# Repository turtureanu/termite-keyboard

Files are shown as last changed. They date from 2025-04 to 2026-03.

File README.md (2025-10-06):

# Termite

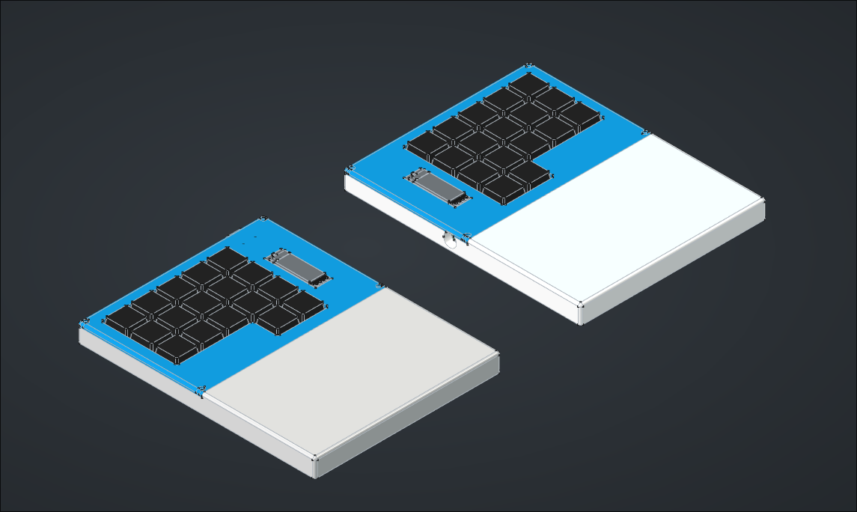
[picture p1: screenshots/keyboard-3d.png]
3D rendering of the assembled keyboard


> [!IMPORTANT]
> **July 26th was the date I submitted this keyboard for review, today on October 6th I noticed that I forgot to add the firmware (which would have been caught by a reviewer).**

> [!IMPORTANT]
> Made for [Hackboard](https://hackpad.hackclub.com/keyboard), which requires having made a macropad as part of [Hackpad *V2*](https://hackpad.hackclub.com/). \
> Here is my Hackpad V2 macropad: [Wirepad](https://github.com/turtureanu/hackpad/tree/main/hackpads/wirepad)

This is a 34-key ortholinear split keyboard with built-in wrist supports, one 0.91" OLED display on each half, and low-profile mechanical Cherry-MX type switches (Gateron). I use a TRRS cable to connect the two halves. The case is 3D printed and uses 5 M2 screws (four M2x12, one M2x4).

For the firmware I'm using KMK.

I created this keyboard as a replacement for my laptop's keyboard, which might fail soon. I wanted an ortholinear split keyboard with fewer keys that would fit the Engram keyboard layout. In the past I designed a similar keyboard with an 0.42" OLED display under each key (inspired by [PolyKybd Split 72](https://github.com/thpoll83/PolyKybd)), but I lost that design due to an accidental mass file deletion that BTRFS couldn't recover.

## Schematics

| Main Schematic                                    |
| ------------------------------------------------- |
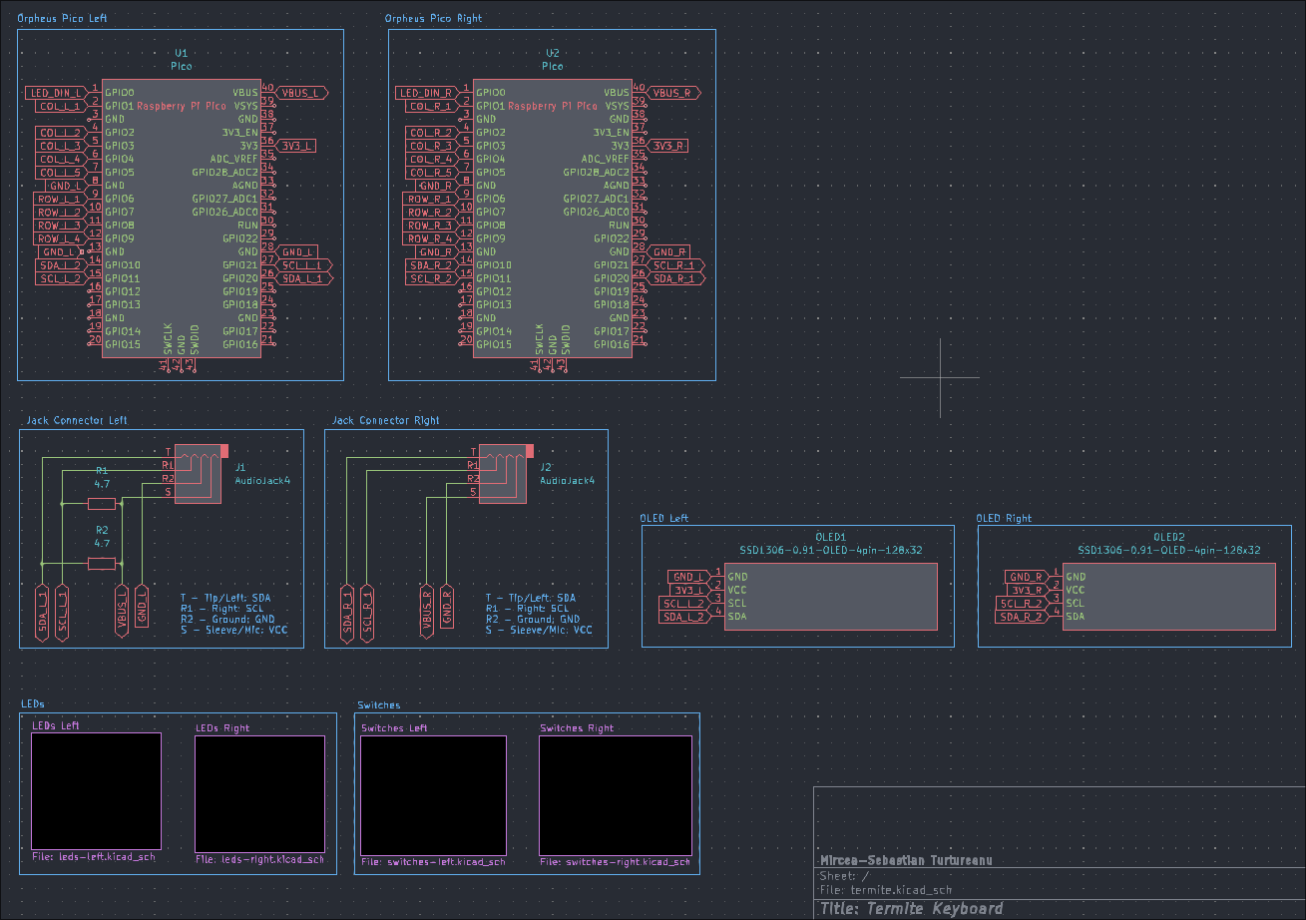
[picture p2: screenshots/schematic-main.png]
Main schematic
|  |

| Left LEDs | Right LEDs |
| --- | --- |
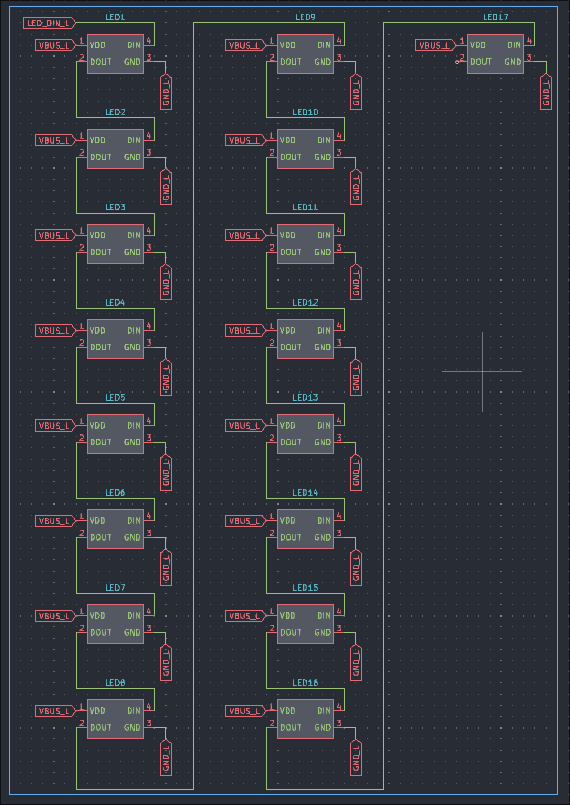
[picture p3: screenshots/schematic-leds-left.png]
Schematic of the left LEDs
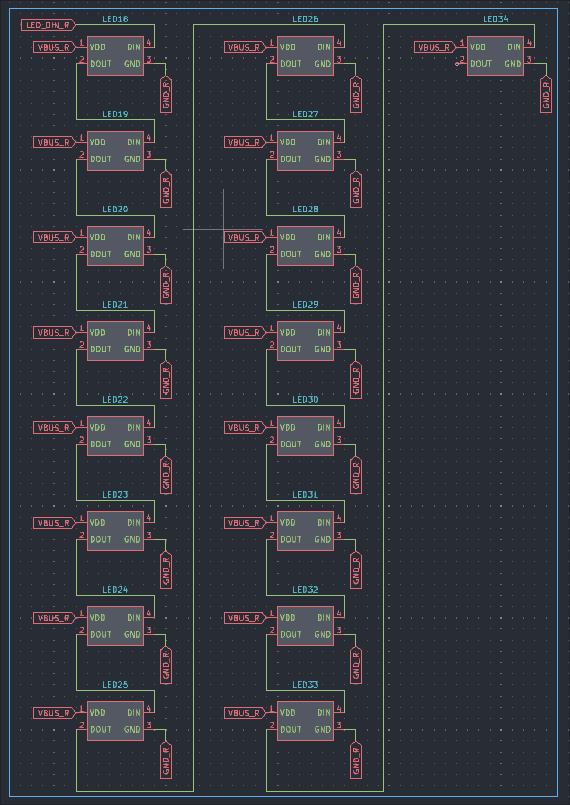
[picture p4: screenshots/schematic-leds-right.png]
Schematic of the right LEDs
|  |  |

| Left Switches | Right Switches |
| --- | --- |
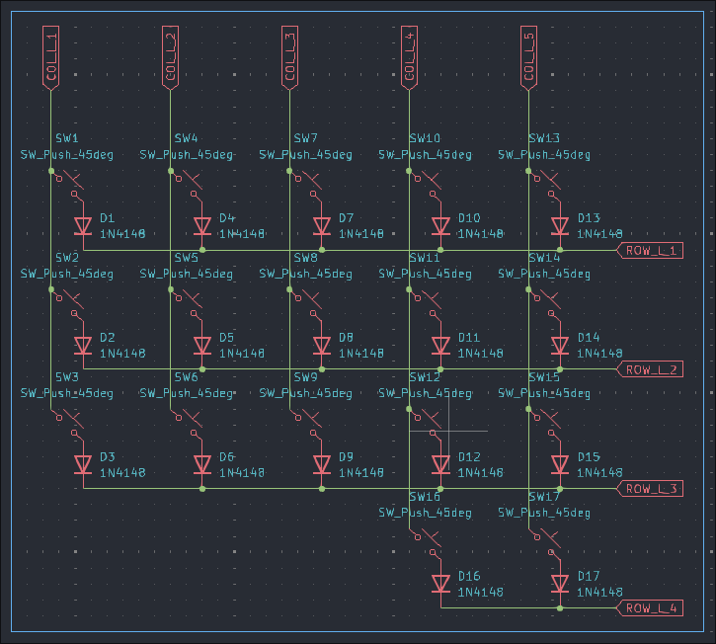
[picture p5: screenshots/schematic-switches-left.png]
Schematic of the left switches
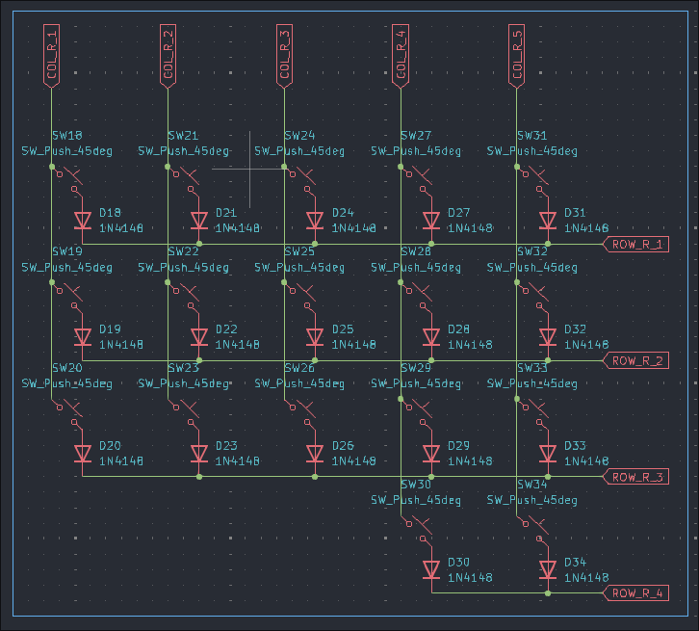
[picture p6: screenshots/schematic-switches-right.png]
Schematic of the right switches
|  |  |

## PCB

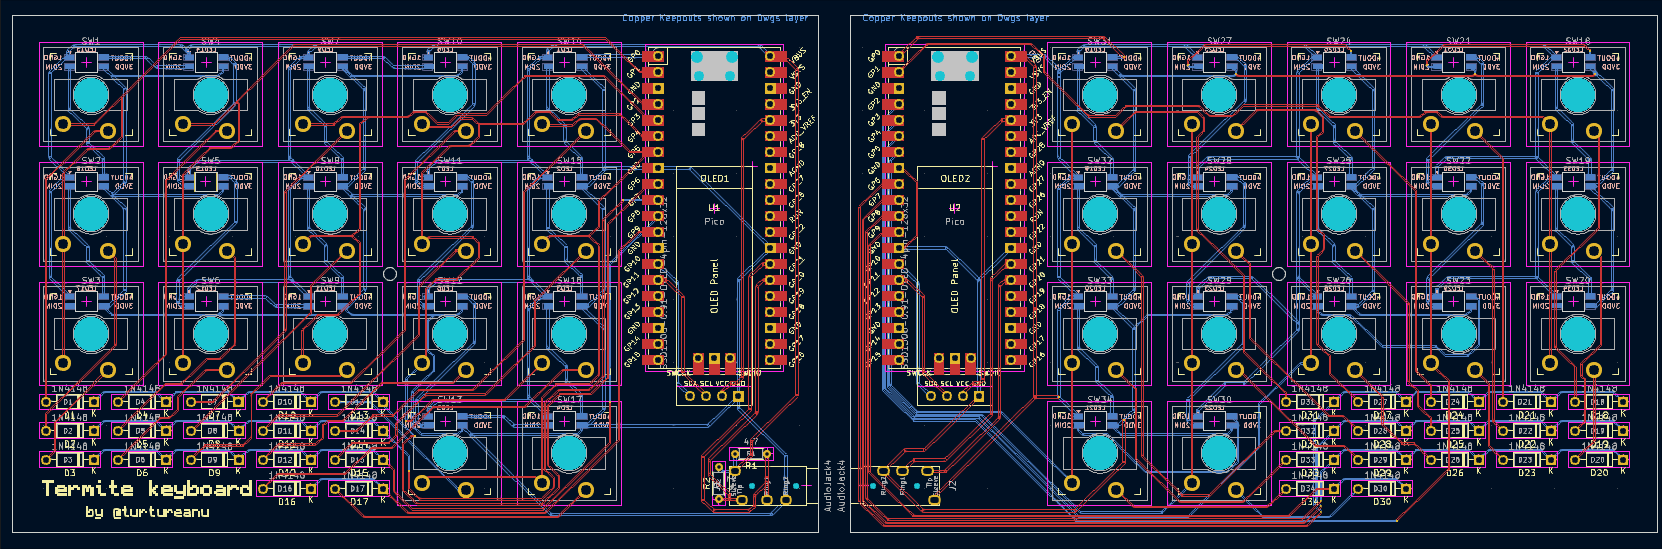
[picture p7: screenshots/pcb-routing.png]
Routing of the PCB

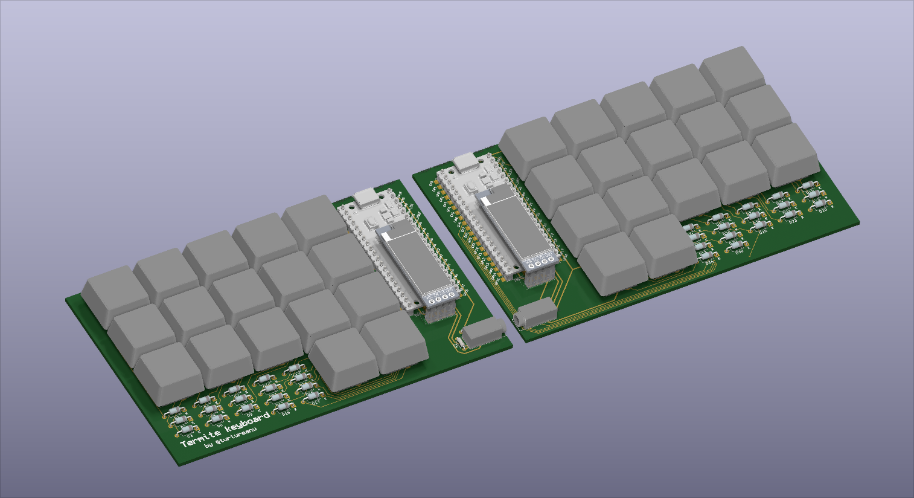
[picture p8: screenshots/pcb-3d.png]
3D rendering of the PCB


> The gerber files can be found in `pcb/gerber`

## BOM

| Name | Sourcing | Category  | Amount | Price (total including shipping) |
|---|---|---|---|---|
| Orpheus Pico | Hack Club  | MCU | 2 | $0 |
| [Gateron Low Profile Switch 2.0 Red](https://www.aliexpress.com/item/1005005385675189.html) | AliExpress | switches  | 35 (set) | $15.85 |
| [Transparent Keycaps with Black Bed](https://www.aliexpress.com/item/1005005984548224.html) | AliExpress | keycaps | 40 (4x 10 pcs set) | $17.55 |
| [SK6812 MINI-E LED](https://www.aliexpress.com/item/1005003056797785.html) | AliExpress | misc | 100 (set) | $5.13 |
| [0.91" White OLED Display](https://www.aliexpress.com/item/1005001572699049.html) | AliExpress | misc | 2 | $3.61 |
| [1N4148 THT Diode](https://www.aliexpress.com/item/4000142272546.html) | AliExpress | misc | 100 (set) | $1.98 |
| [PJ-320A 3.5mm Female Jack Connector](https://www.aliexpress.com/item/4001161286315.html) | AliExpress | misc | 20 (set) | $2.13 |
| [M2x4 Hexagon Countersunk Head Screw with Nut](https://www.aliexpress.com/item/1005006883320887.html)  | AliExpress | fasteners | 50 (set) | $1.75 |
| [M2x12 Hexagon Countersunk Head Screw with Nut](https://www.aliexpress.com/item/1005006883320887.html) | AliExpress | fasteners | 50 (set) | $2.46 |

Switches & keycaps:

- switches: $0.452 per switch
- keycaps: $0.438 per keycap

Fasteners: $4.21 total

Misc:

- LEDs: $0.0513 per LED
- OLED displays: $1.805 per OLED display
- 1N4148 Diodes: 0.0198 per diode
- Jack connector: $0.1065 per jack connector

Misc total: $12.85

JLCPCB cost, if I were to order it myself: $30.04 total (for the entire keyboard, i.e. both halves)

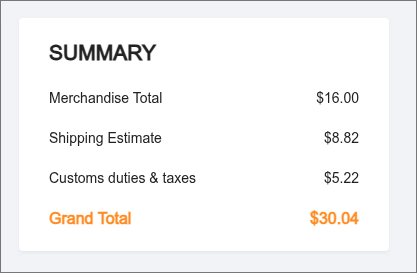
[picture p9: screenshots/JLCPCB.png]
JLCPCB checkout summary


## Credits

- Raspberry Pi Pico model (RPi_Pico_SMD_TH.kicad_mod): https://github.com/ncarandini/KiCad-RP-Pico/
- SK6812-MINI-E (modified): https://github.com/keebio/Keebio-Parts.pretty
- Gateron Switch (SW_Gateron_LowProfile_THT.kicad_mod / modified): https://github.com/siderakb/key-switches.pretty.git
- 0.91 OLED display: https://github.com/gorbachev/KiCad-SSD1306-0.91-OLED-4pin-128x32.pretty/blob/master/SSD1306-0.91-OLED-4pin-128x32.kicad_mod
- Diode (D_DO-35_SOD27_P7.62mm_Horizontal.kicad_mod / modified): https://gitlab.com/kicad/libraries/kicad-footprints/
- PJ-320A 3.5mm 4-pin Jack Connector: https://github.com/nathanhborger/PJ-320A_KiCad_Library
- TRRS-PJ-320A footprint: https://gitlab.com/kicad/libraries/kicad-footprints/

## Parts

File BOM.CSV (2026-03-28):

Name | Sourcing | Sourcing URL | Category | Amount | Price (total including shipping)
Orpheus Pico | Hack Club | N/A | MCU | 2 | $0
Gateron Low Profile Switch 2.0 Red | AliExpress | https://www.aliexpress.com/item/1005005385675189.html | switches | 35 (set) | $15.85
Transparent Keycaps with Black Bed | AliExpress | https://www.aliexpress.com/item/1005005984548224.html | keycaps | 40 (set) | $17.55
SK6812 MINI-E LED | AliExpress | https://www.aliexpress.com/item/1005003056797785.html | misc | 100 (set) | $4.66
0.91" White OLED Display | AliExpress | https://www.aliexpress.com/item/1005001572699049.html | misc | 2 | $3.12
1N4148 THT Diode | AliExpress | https://www.aliexpress.com/item/4000142272546.html | misc | 100 (set) | $1.97
PJ-320A 3.5mm Female Jack Connector | AliExpress | https://www.aliexpress.com/item/4001161286315.html | misc | 20 (set) | $2.13
M2x4 Hexagon Countersunk Head Screw with Nut | AliExpress | https://www.aliexpress.com/item/1005006883320887.html | fasteners | 50 (set) | $1.75
M2x12 Hexagon Countersunk Head Screw with Nut | AliExpress | https://www.aliexpress.com/item/1005006883320887.html | fasteners | 50 (set) | $2.46
Left + Right half PCBs | JLCPCB | https://jlcpcb.com | PCB | 10 (5 per half) | $40.37

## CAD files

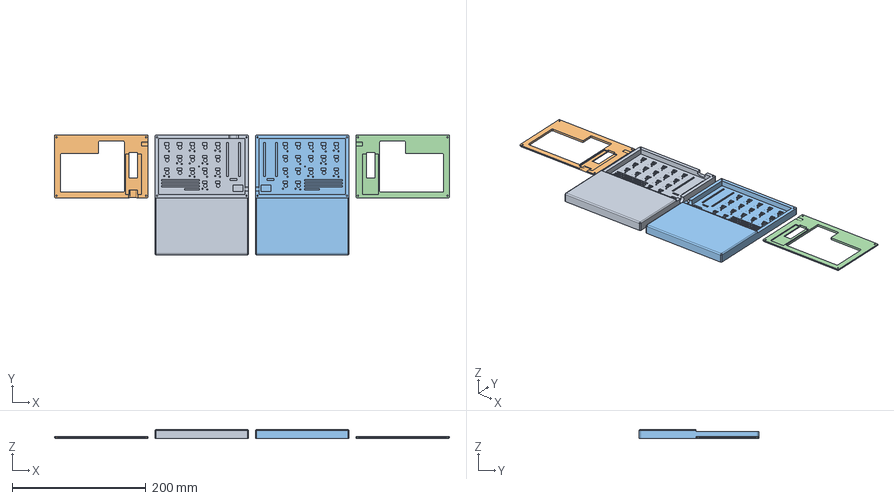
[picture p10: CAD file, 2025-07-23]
cad/termite-full-individual.FCStd
590.0 x 178.9 x 13.6 mm
Bottom001
Top001
Bottom001 (Mirror #1)
Top001 (Mirror #2)

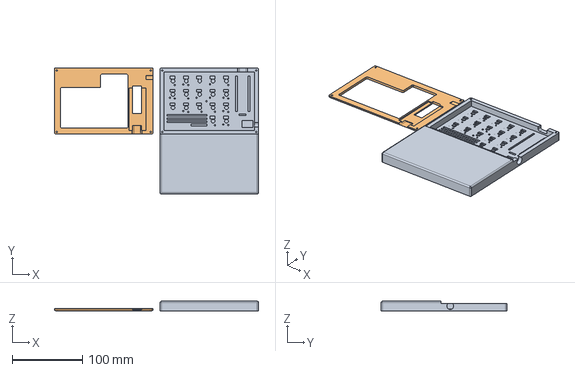
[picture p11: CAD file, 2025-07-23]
cad/termite-left-individual.FCStd
290.0 x 178.9 x 13.6 mm
Bottom001
Top001

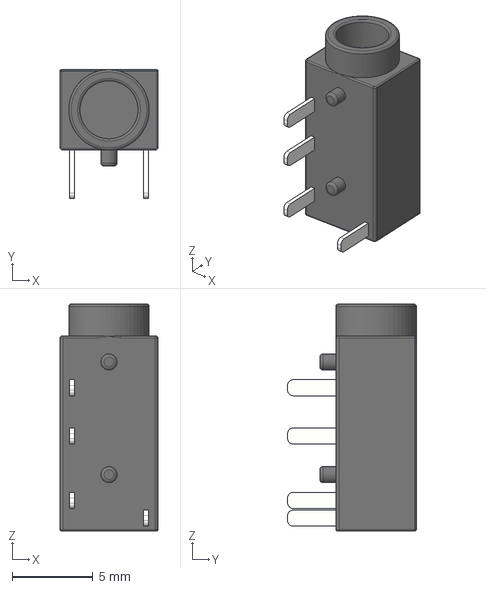
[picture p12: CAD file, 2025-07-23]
pcb/3d-models/PJ-320A.step
6.10 x 8.00 x 14.1 mm

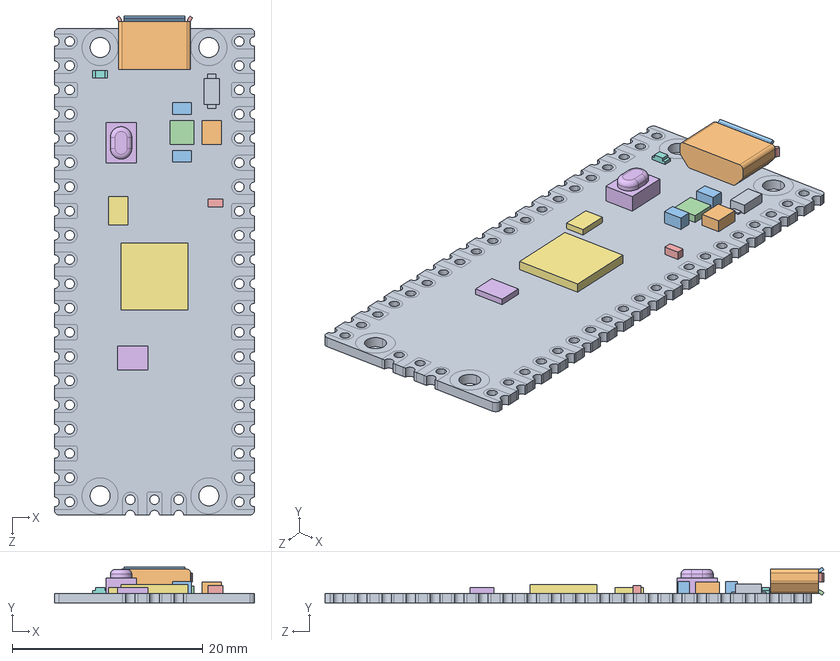
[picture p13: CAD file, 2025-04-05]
pcb/3d-models/Pico-R3.step
21.0 x 3.73 x 52.3 mm
PICO_REF_BOARD.STEP
PICO_REF_USB.STEP
PICO_REF_SWITCH.STEP
PICO_REF_MICROCONTROLLER.STEP
PICO_REF_LED.STEP
PICO_REF_ONSEMI.STEP
PICO_BOURNS.STEP
PICO_MURATA.STEP x 2
PICO_RICHTEK.STEP
PICO_DIODES.STEP
PICO_AEL.STEP
PICO_WINBOND.STEP

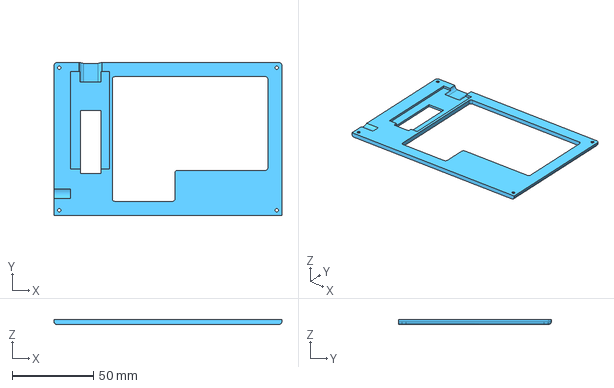
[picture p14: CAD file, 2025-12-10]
production/Left-Top.step
140.0 x 93.9 x 3.00 mm

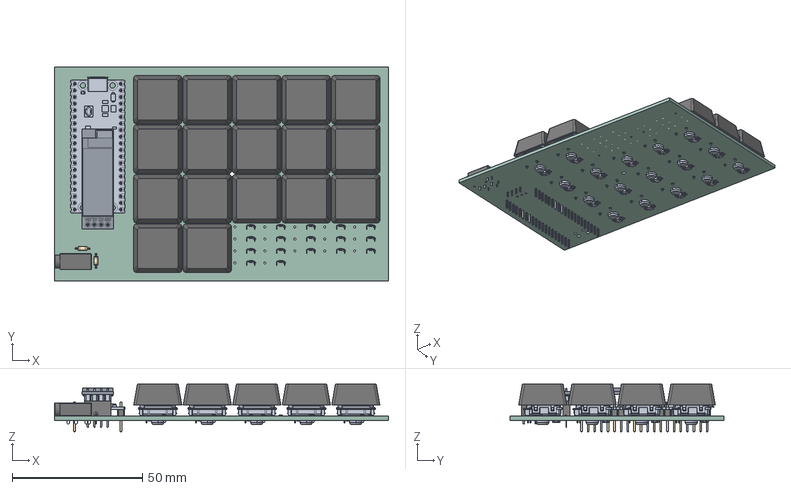
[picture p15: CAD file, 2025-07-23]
cad/termite-right-pcb.step
128.2 x 82.1 x 18.3 mm
RD-014B4CF0776gx x 17
product0 x 17
product1 x 17
product2 x 17
product3 x 17
product4 x 17
product5 x 17
product6 x 17
product7 x 17
product8 x 17
product9 x 17
product10 x 17
product11 x 17
product12 x 17
product13 x 17
product14 x 17
product15 x 17
PICO
PinHeader_1x20_P254mm_Vertical x 2
PJ-3200B v1
R_Axial_DIN0204_L36mm_D16mm_P508mm_Horizontal x 2
PinSocket_1x04_P254mm_Vertical
OLED_0.91_128x32
Pins x 17
termite_PCB

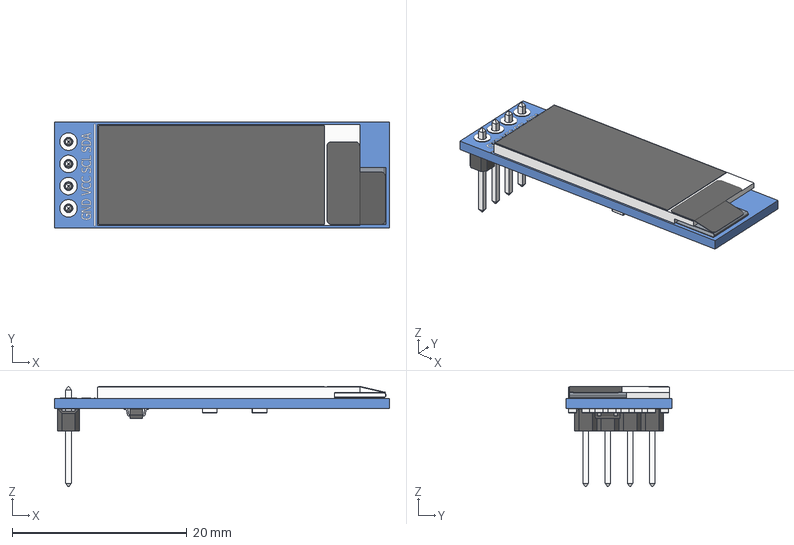
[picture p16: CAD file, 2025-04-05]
pcb/3d-models/oled_0.91_128x32.step
38.3 x 12.1 x 11.5 mm
OLED_0.91_128x32
Pin Header 4 x 1 TH 2.54mm Pitch
RESC-0603 x 13
2SD0601A

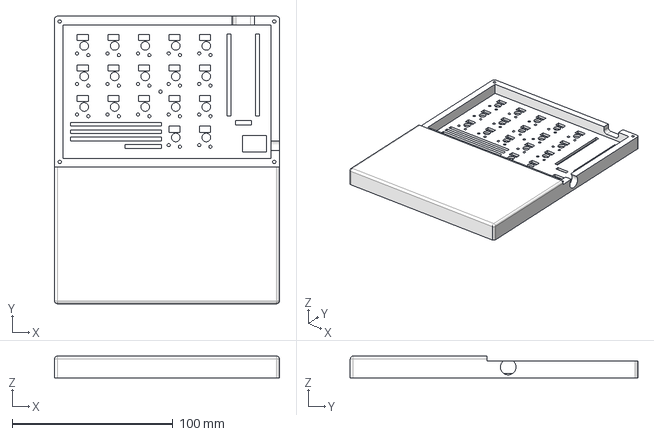
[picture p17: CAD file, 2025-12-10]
production/Left-Bottom.step
140.0 x 178.9 x 13.6 mm

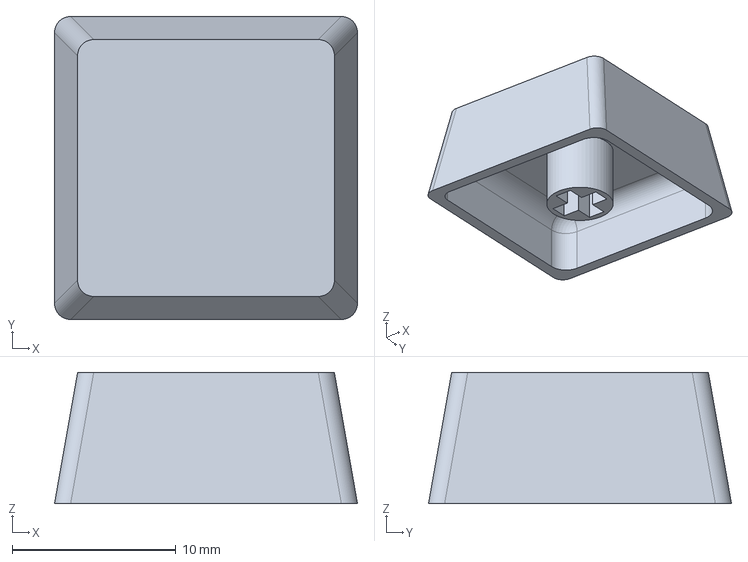
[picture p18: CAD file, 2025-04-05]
pcb/3d-models/keycap.step
18.5 x 18.5 x 8.00 mm

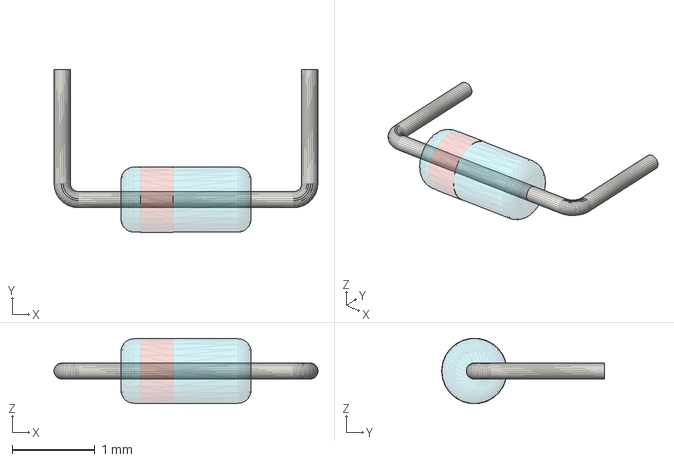
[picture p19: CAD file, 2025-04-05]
pcb/3d-models/D_DO-35_SOD27_P7.62mm_Horizontal.step
3.20 x 1.97 x 0.789 mm

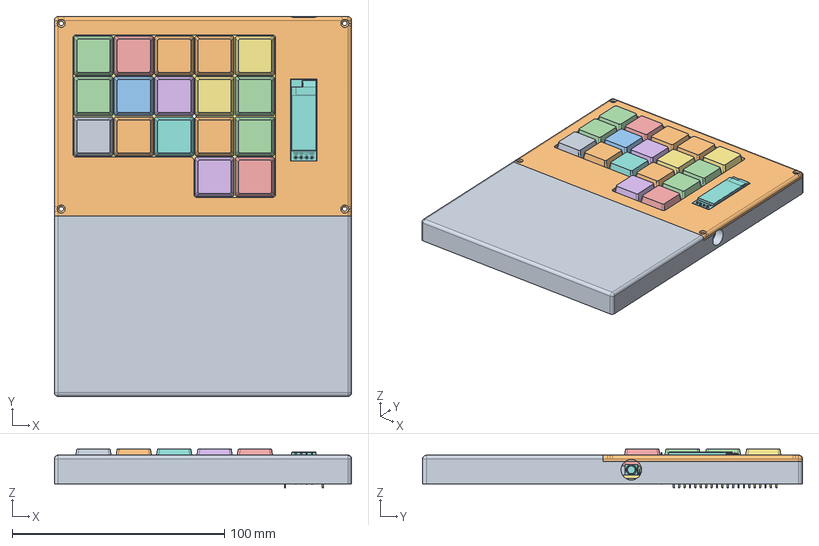
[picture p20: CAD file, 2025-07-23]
cad/termite-right.FCStd
140.0 x 178.9 x 18.3 mm
Bottom
Top
R_Axial_DIN0204_L36mm_D16mm_P508mm_Horizontal
product0
product1
product2
product3
product4
product5
product6
product7
product8
product9
product10
product11
product12
product13
product14
product15
RD-014B4CF0776gx
product001
product002
product003
product004
product005
product006
product007
product008
product009
product010
product011
product012
product013
product014
product015
product016
RD-014B4CF0776gx001
RD-014B4CF0776gx002
RD-014B4CF0776gx003
RD-014B4CF0776gx004
product017
product018
product019
product020
product021
product022
product023
product024
product025
product026
product027
product028
product029
product030
product031
product032
product033
product034
product035
product036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

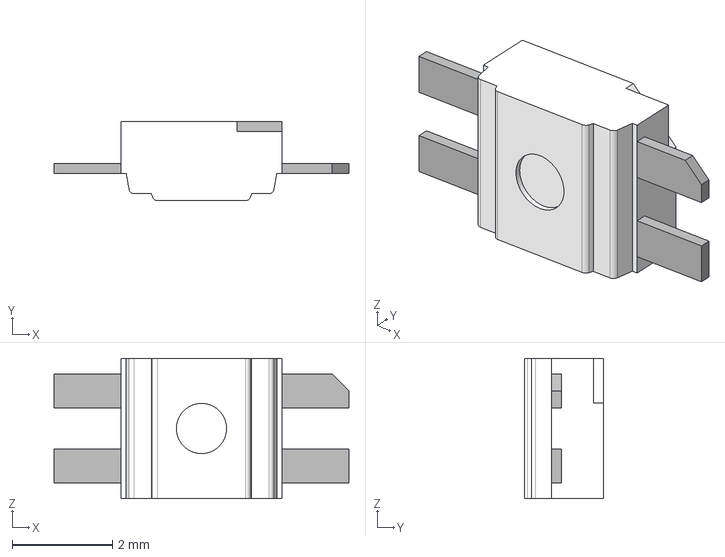
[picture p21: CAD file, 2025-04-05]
pcb/3d-models/SK6812MINI-E v1.step
5.88 x 1.58 x 2.80 mm

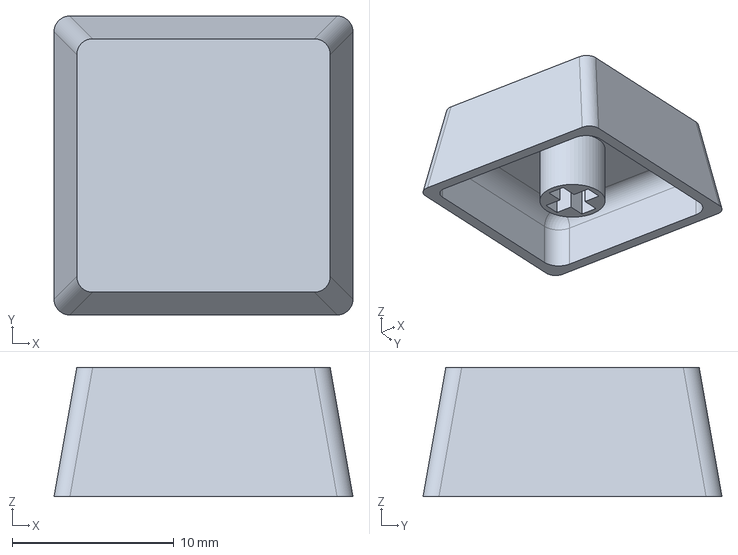
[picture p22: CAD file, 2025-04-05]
cad/keycap.FCStd
18.5 x 18.5 x 8.00 mm

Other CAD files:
production/Termite-Assembled.step
cad/termite-right-individual.FCStd
production/Right-Top.step
cad/termite-left-pcb.step
production/Right-Bottom.step
pcb/3d-models/KS-33-Low-profile-2.0.stp

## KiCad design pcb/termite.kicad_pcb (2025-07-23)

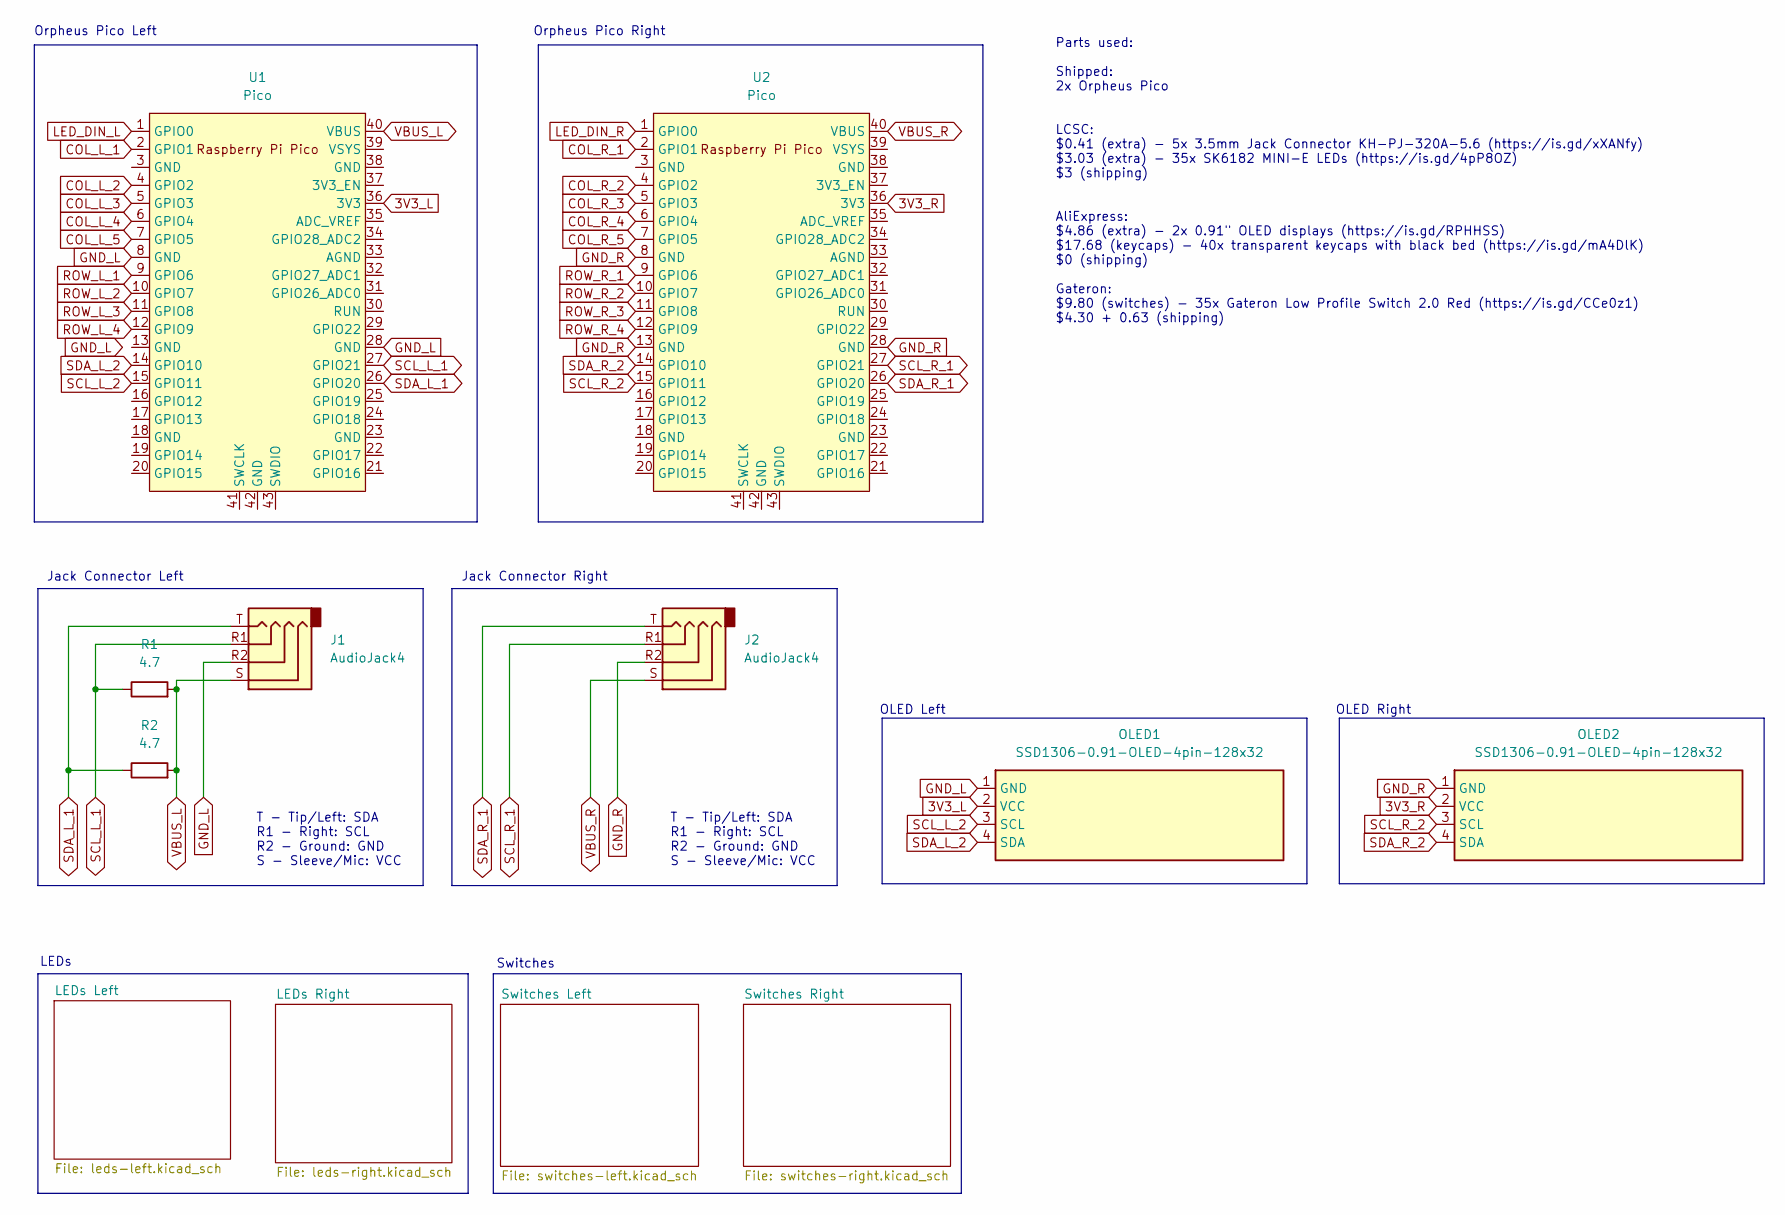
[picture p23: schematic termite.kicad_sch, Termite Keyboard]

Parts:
J1, J2: AudioJack4; TRRS-PJ-320A
OLED1, OLED2: SSD1306-0.91-OLED-4pin-128x32
R1, R2: 4.7; R_Axial_DIN0204_L3.6mm_D1.6mm_P5.08mm_Horizontal
U1, U2: Pico; RPi_Pico_SMD_TH

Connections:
3V3_L: OLED1.2 (VCC), U1.36 (3V3)
3V3_R: OLED2.2 (VCC), U2.36 (3V3)
COL_L_1: U1.2 (GPIO1); also elsewhere on the board
COL_L_2: U1.4 (GPIO2); also elsewhere on the board
COL_L_3: U1.5 (GPIO3); also elsewhere on the board
COL_L_4: U1.6 (GPIO4); also elsewhere on the board
COL_L_5: U1.7 (GPIO5); also elsewhere on the board
COL_R_1: U2.2 (GPIO1); also elsewhere on the board
COL_R_2: U2.4 (GPIO2); also elsewhere on the board
COL_R_3: U2.5 (GPIO3); also elsewhere on the board
COL_R_4: U2.6 (GPIO4); also elsewhere on the board
COL_R_5: U2.7 (GPIO5); also elsewhere on the board
GND_L: J1.R2, OLED1.1 (GND), U1.8 (GND), U1.28 (GND); also elsewhere on the board
GND_R: J2.R2, OLED2.1 (GND), U2.8 (GND), U2.13 (GND), U2.28 (GND); also elsewhere on the board
LED_DIN_L: U1.1 (GPIO0); also elsewhere on the board
LED_DIN_R: U2.1 (GPIO0); also elsewhere on the board
ROW_L_1: U1.9 (GPIO6); also elsewhere on the board
ROW_L_2: U1.10 (GPIO7); also elsewhere on the board
ROW_L_3: U1.11 (GPIO8); also elsewhere on the board
ROW_L_4: U1.12 (GPIO9); also elsewhere on the board
ROW_R_1: U2.9 (GPIO6); also elsewhere on the board
ROW_R_2: U2.10 (GPIO7); also elsewhere on the board
ROW_R_3: U2.11 (GPIO8); also elsewhere on the board
ROW_R_4: U2.12 (GPIO9); also elsewhere on the board
SCL_L_1: J1.R1, R1.1, U1.27 (GPIO21)
SCL_L_2: OLED1.3 (SCL), U1.15 (GPIO11)
SCL_R_1: J2.R1, U2.27 (GPIO21)
SCL_R_2: OLED2.3 (SCL), U2.15 (GPIO11)
SDA_L_1: J1.T, R2.1, U1.26 (GPIO20)
SDA_L_2: OLED1.4 (SDA), U1.14 (GPIO10)
SDA_R_1: J2.T, U2.26 (GPIO20)
SDA_R_2: OLED2.4 (SDA), U2.14 (GPIO10)
VBUS_L: J1.S, R1.2, R2.2, U1.40 (VBUS); also elsewhere on the board
VBUS_R: J2.S, U2.40 (VBUS); also elsewhere on the board

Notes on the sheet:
OLED Right
LEDs
T - Tip/Left: SDA R1 - Right: SCL R2 - Ground: GND S - Sleeve/Mic: VCC
Jack Connector Right
Orpheus Pico Right
OLED Left
Parts used: Shipped: 2x Orpheus Pico LCSC: $0.41 (extra) - 5x 3.5mm Jack Connector KH-PJ-320A-5.6 (https://is.gd/xXANfy) $3.03 (extra) - 35x SK6182 MINI-E LEDs (https://is.gd/4pP8OZ) $3 (shipping) AliExpress: $4.86 (extra) - 2x 0.91" OLED displays (https://is.gd/RPHHSS) $17.68 (keycaps) - 40x trans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
Jack Connector Left
Switches
Orpheus Pico Left

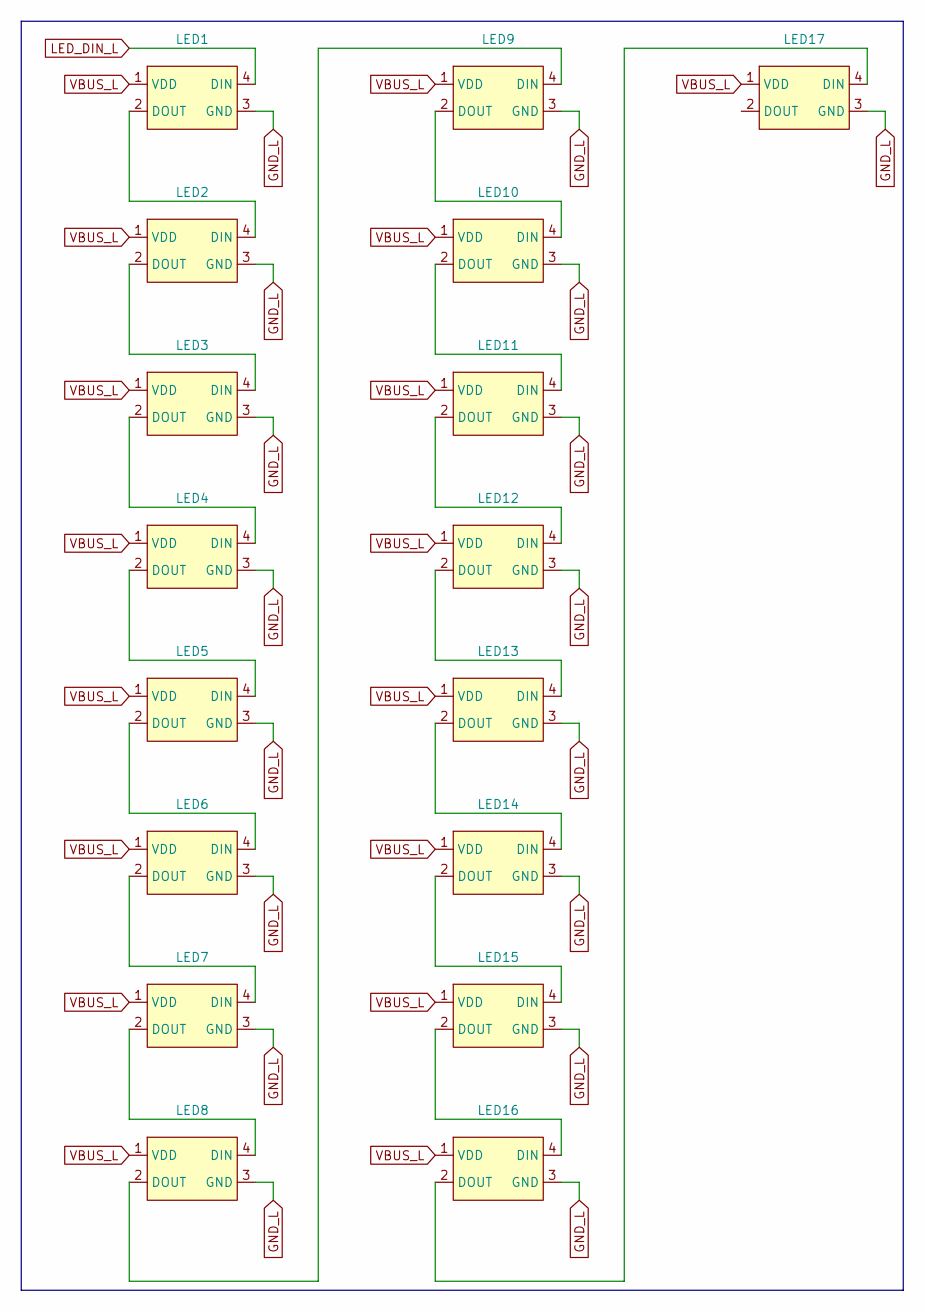
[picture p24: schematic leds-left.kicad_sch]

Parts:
LED1, LED2, LED3, LED4, LED5, LED6, LED7, LED8, LED9, LED10, LED11, LED12, LED13, LED14, LED15, LED16, LED17: SK6812-MINI-E

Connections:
GND_L: LED1.3 (GND), LED2.3 (GND), LED3.3 (GND), LED4.3 (GND), LED5.3 (GND), LED6.3 (GND), LED7.3 (GND), LED8.3 (GND), LED9.3 (GND), LED10.3 (GND), LED11.3 (GND), LED12.3 (GND), LED13.3 (GND), LED14.3 (GND), LED15.3 (GND), LED16.3 (GND), LED17.3 (GND); also elsewhere on the board
LED_DIN_L: LED1.4 (DIN); also elsewhere on the board
unnamed: LED1.2 (DOUT), LED2.4 (DIN)
unnamed: LED2.2 (DOUT), LED3.4 (DIN)
unnamed: LED3.2 (DOUT), LED4.4 (DIN)
unnamed: LED4.2 (DOUT), LED5.4 (DIN)
unnamed: LED5.2 (DOUT), LED6.4 (DIN)
unnamed: LED6.2 (DOUT), LED7.4 (DIN)
unnamed: LED7.2 (DOUT), LED8.4 (DIN)
unnamed: LED8.2 (DOUT), LED9.4 (DIN)
unnamed: LED9.2 (DOUT), LED10.4 (DIN)
unnamed: LED10.2 (DOUT), LED11.4 (DIN)
unnamed: LED11.2 (DOUT), LED12.4 (DIN)
unnamed: LED12.2 (DOUT), LED13.4 (DIN)
unnamed: LED13.2 (DOUT), LED14.4 (DIN)
unnamed: LED14.2 (DOUT), LED15.4 (DIN)
unnamed: LED15.2 (DOUT), LED16.4 (DIN)
unnamed: LED16.2 (DOUT), LED17.4 (DIN)
VBUS_L: LED1.1 (VDD), LED2.1 (VDD), LED3.1 (VDD), LED4.1 (VDD), LED5.1 (VDD), LED6.1 (VDD), LED7.1 (VDD), LED8.1 (VDD), LED9.1 (VDD), LED10.1 (VDD), LED11.1 (VDD), LED12.1 (VDD), LED13.1 (VDD), LED14.1 (VDD), LED15.1 (VDD), LED16.1 (VDD), LED17.1 (VDD); also elsewhere on the board

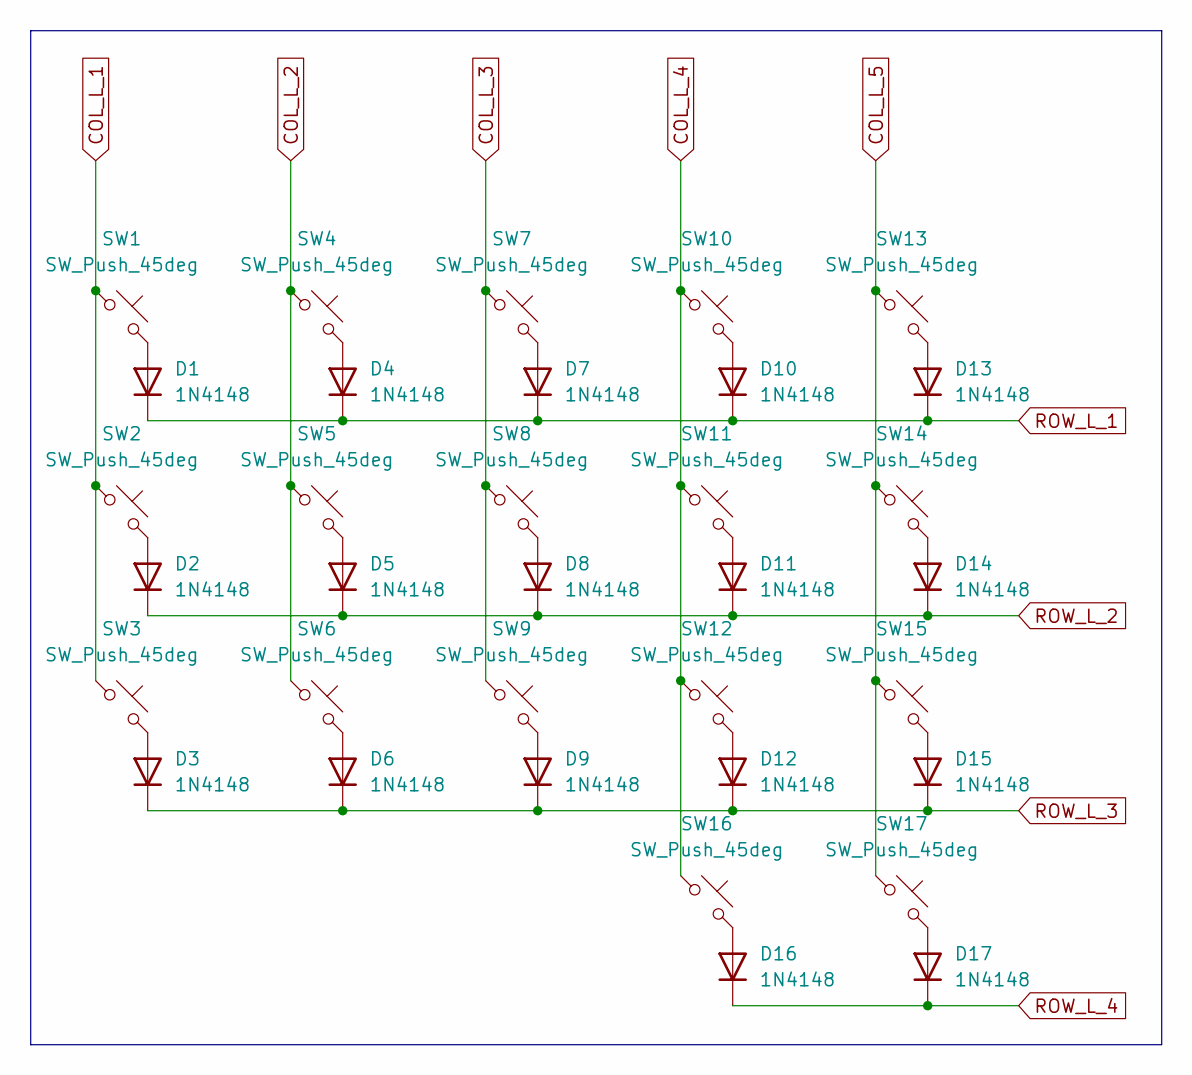
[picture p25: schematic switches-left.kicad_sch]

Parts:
D1, D2, D3, D4, D5, D6, D7, D8, D9, D10, D11, D12, D13, D14, D15, D16, D17: 1N4148; D_DO-35_SOD27_P7.62mm_Horizontal
SW1, SW2, SW3, SW4, SW5, SW6, SW7, SW8, SW9, SW10, SW11, SW12, SW13, SW14, SW15, SW16, SW17: SW_Push_45deg; SW_Gateron_LowProfile_THT

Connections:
COL_L_1: SW1.1, SW2.1, SW3.1; also elsewhere on the board
COL_L_2: SW4.1, SW5.1, SW6.1; also elsewhere on the board
COL_L_3: SW7.1, SW8.1, SW9.1; also elsewhere on the board
COL_L_4: SW10.1, SW11.1, SW12.1, SW16.1; also elsewhere on the board
COL_L_5: SW13.1, SW14.1, SW15.1, SW17.1; also elsewhere on the board
unnamed: D1.2 (A), SW1.2
unnamed: D2.2 (A), SW2.2
unnamed: D3.2 (A), SW3.2
unnamed: D4.2 (A), SW4.2
unnamed: D5.2 (A), SW5.2
unnamed: D6.2 (A), SW6.2
unnamed: D7.2 (A), SW7.2
unnamed: D8.2 (A), SW8.2
unnamed: D9.2 (A), SW9.2
unnamed: D10.2 (A), SW10.2
unnamed: D11.2 (A), SW11.2
unnamed: D12.2 (A), SW12.2
unnamed: D13.2 (A), SW13.2
unnamed: D14.2 (A), SW14.2
unnamed: D15.2 (A), SW15.2
unnamed: D16.2 (A), SW16.2
unnamed: D17.2 (A), SW17.2
ROW_L_1: D1.1 (K), D4.1 (K), D7.1 (K), D10.1 (K), D13.1 (K); also elsewhere on the board
ROW_L_2: D2.1 (K), D5.1 (K), D8.1 (K), D11.1 (K), D14.1 (K); also elsewhere on the board
ROW_L_3: D3.1 (K), D6.1 (K), D9.1 (K), D12.1 (K), D15.1 (K); also elsewhere on the board
ROW_L_4: D16.1 (K), D17.1 (K); also elsewhere on the board

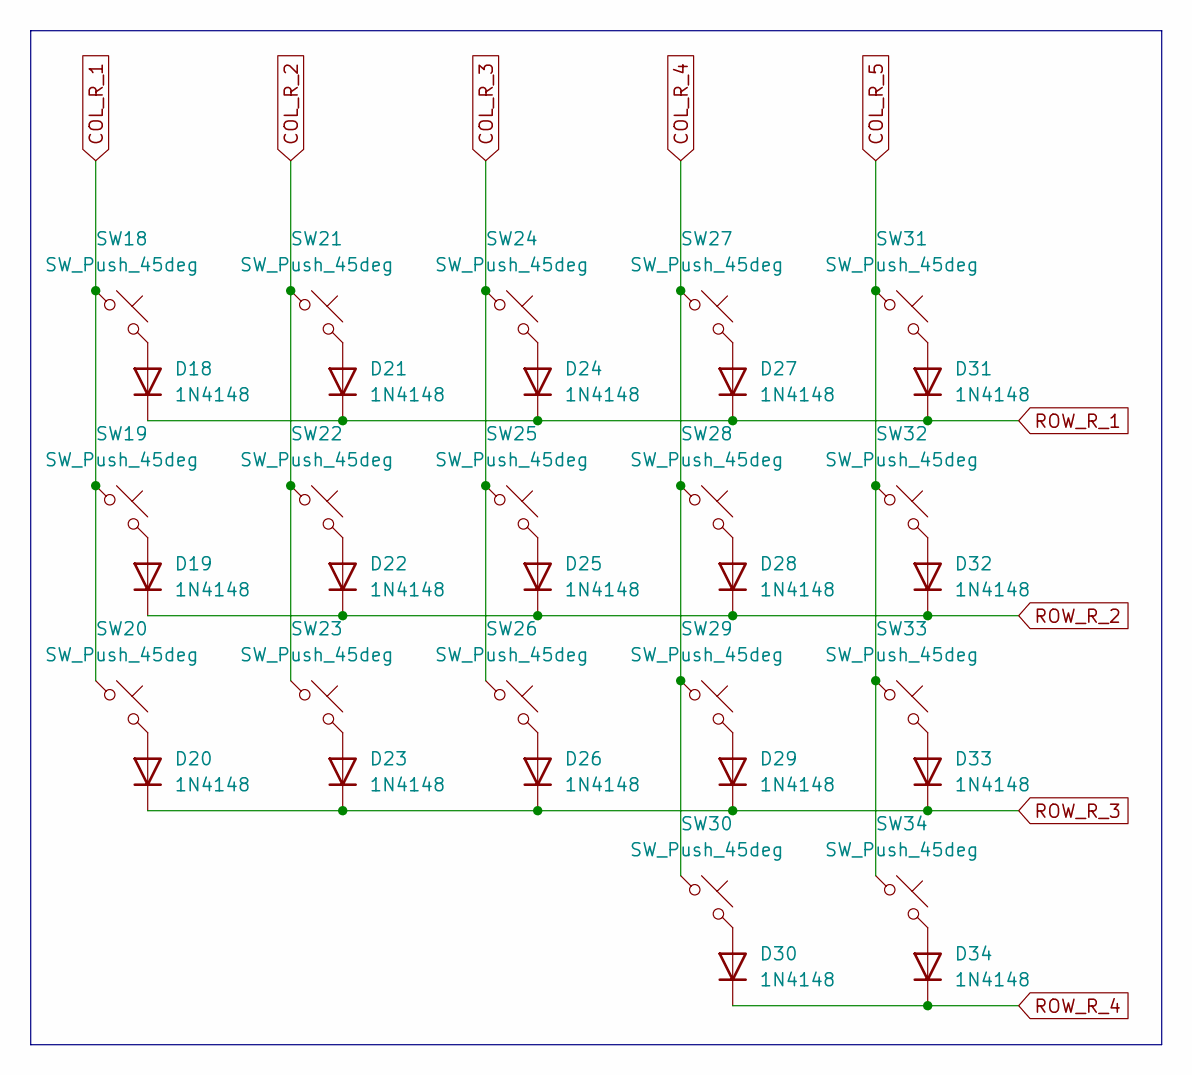
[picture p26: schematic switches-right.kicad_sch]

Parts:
D18, D19, D20, D21, D22, D23, D24, D25, D26, D27, D28, D29, D30, D31, D32, D33, D34: 1N4148; D_DO-35_SOD27_P7.62mm_Horizontal
SW18, SW19, SW20, SW21, SW22, SW23, SW24, SW25, SW26, SW27, SW28, SW29, SW30, SW31, SW32, SW33, SW34: SW_Push_45deg; SW_Gateron_LowProfile_THT

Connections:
COL_R_1: SW18.1, SW19.1, SW20.1; also elsewhere on the board
COL_R_2: SW21.1, SW22.1, SW23.1; also elsewhere on the board
COL_R_3: SW24.1, SW25.1, SW26.1; also elsewhere on the board
COL_R_4: SW27.1, SW28.1, SW29.1, SW30.1; also elsewhere on the board
COL_R_5: SW31.1, SW32.1, SW33.1, SW34.1; also elsewhere on the board
unnamed: D18.2 (A), SW18.2
unnamed: D19.2 (A), SW19.2
unnamed: D20.2 (A), SW20.2
unnamed: D21.2 (A), SW21.2
unnamed: D22.2 (A), SW22.2
unnamed: D23.2 (A), SW23.2
unnamed: D24.2 (A), SW24.2
unnamed: D25.2 (A), SW25.2
unnamed: D26.2 (A), SW26.2
unnamed: D27.2 (A), SW27.2
unnamed: D28.2 (A), SW28.2
unnamed: D29.2 (A), SW29.2
unnamed: D30.2 (A), SW30.2
unnamed: D31.2 (A), SW31.2
unnamed: D32.2 (A), SW32.2
unnamed: D33.2 (A), SW33.2
unnamed: D34.2 (A), SW34.2
ROW_R_1: D18.1 (K), D21.1 (K), D24.1 (K), D27.1 (K), D31.1 (K); also elsewhere on the board
ROW_R_2: D19.1 (K), D22.1 (K), D25.1 (K), D28.1 (K), D32.1 (K); also elsewhere on the board
ROW_R_3: D20.1 (K), D23.1 (K), D26.1 (K), D29.1 (K), D33.1 (K); also elsewhere on the board
ROW_R_4: D30.1 (K), D34.1 (K); also elsewhere on the board

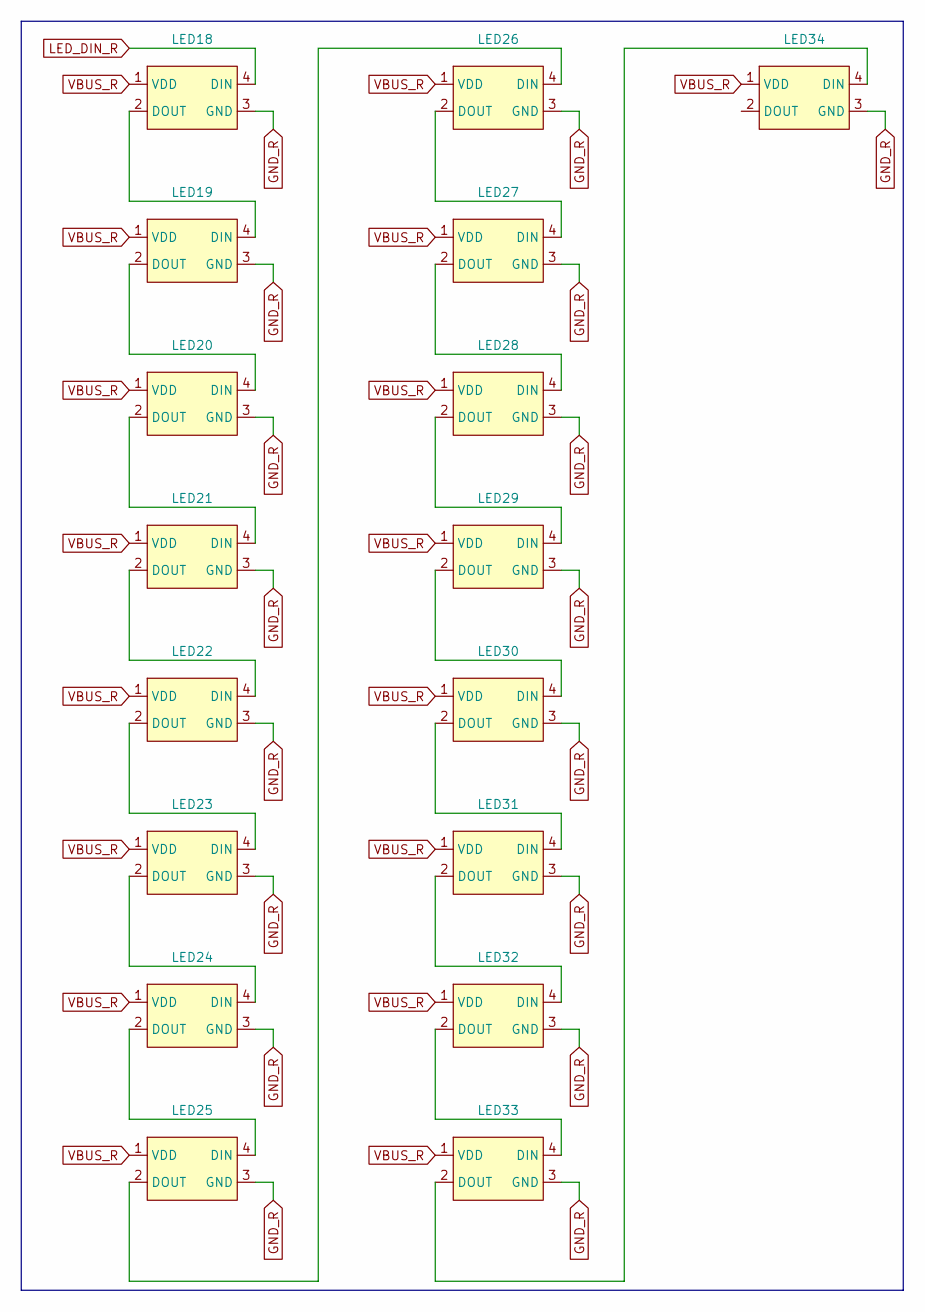
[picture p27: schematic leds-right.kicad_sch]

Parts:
LED18, LED19, LED20, LED21, LED22, LED23, LED24, LED25, LED26, LED27, LED28, LED29, LED30, LED31, LED32, LED33, LED34: SK6812-MINI-E

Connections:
GND_R: LED18.3 (GND), LED19.3 (GND), LED20.3 (GND), LED21.3 (GND), LED22.3 (GND), LED23.3 (GND), LED24.3 (GND), LED25.3 (GND), LED26.3 (GND), LED27.3 (GND), LED28.3 (GND), LED29.3 (GND), LED30.3 (GND), LED31.3 (GND), LED32.3 (GND), LED33.3 (GND), LED34.3 (GND); also elsewhere on the board
LED_DIN_R: LED18.4 (DIN); also elsewhere on the board
unnamed: LED18.2 (DOUT), LED19.4 (DIN)
unnamed: LED19.2 (DOUT), LED20.4 (DIN)
unnamed: LED20.2 (DOUT), LED21.4 (DIN)
unnamed: LED21.2 (DOUT), LED22.4 (DIN)
unnamed: LED22.2 (DOUT), LED23.4 (DIN)
unnamed: LED23.2 (DOUT), LED24.4 (DIN)
unnamed: LED24.2 (DOUT), LED25.4 (DIN)
unnamed: LED25.2 (DOUT), LED26.4 (DIN)
unnamed: LED26.2 (DOUT), LED27.4 (DIN)
unnamed: LED27.2 (DOUT), LED28.4 (DIN)
unnamed: LED28.2 (DOUT), LED29.4 (DIN)
unnamed: LED29.2 (DOUT), LED30.4 (DIN)
unnamed: LED30.2 (DOUT), LED31.4 (DIN)
unnamed: LED31.2 (DOUT), LED32.4 (DIN)
unnamed: LED32.2 (DOUT), LED33.4 (DIN)
unnamed: LED33.2 (DOUT), LED34.4 (DIN)
VBUS_R: LED18.1 (VDD), LED19.1 (VDD), LED20.1 (VDD), LED21.1 (VDD), LED22.1 (VDD), LED23.1 (VDD), LED24.1 (VDD), LED25.1 (VDD), LED26.1 (VDD), LED27.1 (VDD), LED28.1 (VDD), LED29.1 (VDD), LED30.1 (VDD), LED31.1 (VDD), LED32.1 (VDD), LED33.1 (VDD), LED34.1 (VDD); also elsewhere on the board

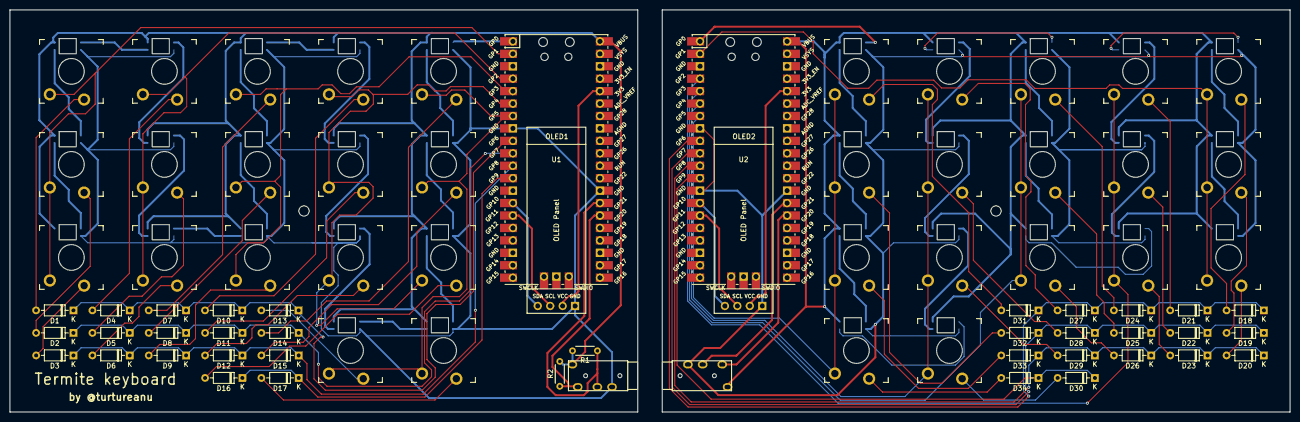
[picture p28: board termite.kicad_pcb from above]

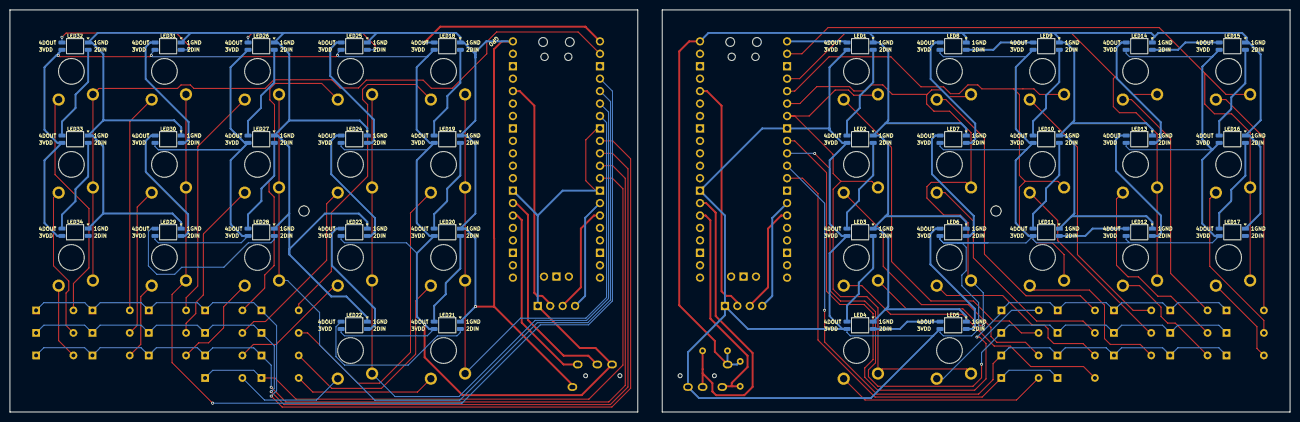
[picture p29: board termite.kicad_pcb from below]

Board: 2 copper layers, 261.4 x 82.1 mm, 110 parts (34 on the bottom side), 100 nets.

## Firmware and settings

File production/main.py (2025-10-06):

import board
import busio
from storage import getmount

from kmk.kmk_keyboard import KMKKeyboard
from kmk.keys import KC
from kmk.scanners import DiodeOrientation
from kmk.modules.split import Split, SplitType, SplitSide
from kmk.modules.layers import Layers
from kmk.extensions.rgb import RGB
from kmk.extensions.display import Display, TextEntry
from kmk.extensions.display.ssd1306 import SSD1306

keyboard = KMKKeyboard()
keyboard.debug_enabled = False

# https://github.com/KMKfw/kmk_firmware/blob/main/docs/en/split_keyboards.md#split_side
side = SplitSide.RIGHT if str(getmount('/').label)[-1] == 'R' else SplitSide.LEFT

keyboard.col_pins = (board.GP1, board.GP2, board.GP3, board.GP4, board.GP5)
keyboard.row_pins = (board.GP6, board.GP7, board.GP8, board.GP9)
keyboard.diode_orientation = DiodeOrientation.COL2ROW

# Layers support
# https://github.com/KMKfw/kmk_firmware/blob/main/docs/en/layers.md
layers = Layers()
keyboard.modules.append(layers)

# Split support
# https://github.com/KMKfw/kmk_firmware/blob/main/docs/en/split_keyboards.md#split_side
split = Split(
    split_type=SplitType.UART,
    split_side=side,
    split_target_left=True, # main split is left (to which the USB cable will be connceted)
    data_pin=board.GP20,         # Jack connector SDA_1 (1)
    data_pin2=board.GP21,        # Jack connector SCL_1 (2)
    uart_flip=True,              # TX is connected to TX (noticed this just now, but thankfully there's this option, that can flip them)
    # use_pio=True,               # not sure, if I need this
    uart_interval=10,
)
keyboard.modules.append(split)

# --- RGB SK6812 per-key LEDs ---
rgb = RGB(
    pixel_pin=board.GP0,   # LED_DIN
    num_pixels=17,
    val=150, # brightness
    rgb_order=(0, 1, 2), # why is (1, 0, 2)/GRB the default?!
)
keyboard.extensions.append(rgb)

# OLED
i2c = busio.I2C(board.GP11, board.GP10)
display_driver = SSD1306(i2c=i2c)
display = Display(
    display=display_driver,
    width=128,
    height=32,
    entries=[
        TextEntry(text="HELLO:", x=0, y=0),
        TextEntry(text="WORLD", x=0, y=30)
        brightness=1.0
    ],
)
keyboard.extensions.append(display)

# Layout
LAYOUT_LEFT = [
    KC.B,    KC.Y,    KC.O,    KC.U,    KC.QUOT,
    KC.C,    KC.I,    KC.E,    KC.A,    KC.COMM,
    KC.G,    KC.X,    KC.J,    KC.K,    KC.MINS,
                            KC.LSFT,    KC.SPC,
]

LAYOUT_RIGHT = [
    KC.SCLN,  KC.L,    KC.D,    KC.W,    KC.V,
    KC.DOT,   KC.H,    KC.T,    KC.S,    KC.N,
    KC.SLSH,  KC.R,    KC.M,    KC.F,    KC.P,
    KC.ENT,   KC.MO(1)
]

MO_FN = KC.MO(1)

keyboard.keymap = [
    LAYOUT_LEFT + LAYOUT_RIGHT,
    # layer 1
    [
        KC.N1, KC.N2, KC.N3, KC.N4, KC.N5,
        KC.EXLM, KC.AT, KC.HASH, KC.DLR, KC.PERC,
        KC.GRV, KC.TILD, KC.NO, KC.NO, KC.NO,
        KC.NO, KC.NO

        KC.CIRC, KC.AMPR, KC.ASTR, KC.LPRN, KC.RPRN,
        KC.NO, KC.NO, KC.NO, KC.NO, KC.NO,
        KC.NO, KC.NO, KC.NO, KC.NO, KC.NO,
        KC.NO, KC.NO
    ],
]

if __name__ == '__main__':
    keyboard.go()

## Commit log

2025-04-05 add: project files (dirty)
    [D_DO-35_SOD27_P7.62mm_Horizontal.step, KS-33-Low-profile-2.0.stp, Pico-R3.step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]
2025-06-21 fix: bring jack connectors to the edge
    [termite.kicad_pcb]
2025-07-23 feat: finish case + reorganize project structure
    [D_DO-35_SOD27_P7.62mm_Horizontal.step, KS-33-Low-profile-2.0.stp, PJ-320A.step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]
2025-07-23 ignore: termite backups
    [D_DO-35_SOD27_P7.62mm_Horizontal.step, KS-33-Low-profile-2.0.stp, Pico-R3.step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]
2025-07-26 add: description, screenshots, BOM
    [BOM.CSV]
2025-07-26 add: gerber files for both halves
    [designators.csv, positions.csv]
2025-10-29 add: production directory
    [designators.csv, positions.csv]
2025-12-10 fix: production directory file structure
    [Left-Bottom.step, Left-Top.step, Right-Bottom.step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]
2026-01-16 add: assembled keyboard step
    [Termite-Assembled.step]
2026-03-28 Add Left & Right half PCBs to BOM
    [BOM.CSV]
